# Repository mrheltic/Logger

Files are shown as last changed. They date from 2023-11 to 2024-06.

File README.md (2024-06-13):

# Logger










## 📝 Table of Contents
- [About](#🧐-about)
- [Getting Started](#🏁-getting-started)
- [Hardware](#🔧-hardware-required)
- [Description](#description)
- [Theoretical Notions](#theoretical-notions)
- [Code](#⌨️-code)
- [Display Mode](#🖥️-display-mode)
- [SD Mode](#💾-sd-mode)
- [Serial Mode](#💻-serial-mode)
- [Built using](#⛏️-built-using)
- [Contributing](#🫂-contributing)
- [Authors](#✍️-authors)
- [Repo Activity](#repo-activity)
- [License](#license)
- [Acknowledgments](#🎉-acknowledgments)

## 🧐 About
This project is a data acquisition system built using an ESP32 microcontroller board. The system incorporates an ADS1115 analog-to-digital converter, an SSD1306 display, and three buttons for user interaction. It is designed to store data on an SD card or send it to a pc for further analysis.

### Features

- Acquisition of analog sensor data using ADS1115 ADC
- Real-time display of sensor readings on SSD1306 OLED display
- User interaction through three buttons for control and configuration
- Storage of acquired data on an SD card for offline access
- Transmission of data to a computer for centralized analysis

## 🔧 Hardware Required

## 🏁 Getting Started

### Prerequisites

- Arduino IDE or Visual Studio Code (with PlatformIO)
- ESP32 board manager for Arduino IDE
- Libraries:
  - Adafruit ADS1X15 (for ADS1115)
  - Adafruit SSD1306 (for SSD1306 display)
  - SD (for SD card storage)
  - <other libraries as required>

### Installation

<details open>
<summary><i>Installation using Arduino IDE</i></summary>

- Clone or download the project repository from GitHub.
- Open the Arduino IDE and install the ESP32 board manager if not already installed.
- Connect the hardware components as per the provided circuit diagram.
- Install the required libraries using the Arduino Library Manager.
- Upload the code to the ESP32 board using the Arduino IDE.
- Monitor the serial output to ensure successful connection to the sensors.
- Verify the functionality by checking the sensor readings on the SSD1306 display and the data storage on the SD card.
</details>

<details open>
<summary><i>Installation using Visual Studio Code</i></summary>

- Clone or download the project repository from GitHub.
- Open VS and compile the software (changing the details on platform.ini according to your hardware).
- Connect the hardware components as per the provided circuit diagram.
- Upload the code to the ESP32 board using the upload tool.
- Monitor the serial output to ensure successful connection to the sensors.
- Verify the functionality by checking the sensor readings on the SSD1306 display and the data storage on the SD card.

</details>

## Description

## ⌨️ Code

All the code was written using the arduino Framework, for an ESP32. This gave us significant advantages in terms of ease of writing, online documentation, and especially in terms of click-through, which is considerably greater than for an arduino Uno. We followed a kind of MVC model, where each component is separate from the others and deals only with the things it is responsible for, invoking higher-level primitives. This allowed us to manage different components more smoothly.

### Main

The main substantially is a method wrapper and deals at a higher level with handling scrolling through the various menus. Initially (in setup) it asks the controller to initialize devices (the basic ones, such as buttons, screen, ...)

```cpp
while (!initializeDevices()){
}

updateMenu();
```

After this handles menu selection

```cpp
if (stateMenu)
{
  if (goDown())
  {
    menu++;
  }
  if (goUp())
  {
    menu--;
  }
  if (select())
  {
    executeAction(); //Enters in the selected menu
  }
}
```

### Controller

The controller is the component that manages all component behavior and is directly responsible for making measurements. Besides that it initializes all the devices and the serial. The initializations that are done can be blocking or non-blocking, depending on the type of component we want to initialize: a failure of the fundamental components results in a program block inside a loop, which will not allow the execution of the remaining code, while the other components may not be initialized at all. The reference with respect to the success or failure of initialization we have it by returning a boolean value true when the method is terminated, so it does not take into account subsequent failures. The whole initial part is devoted to declaring all pins connected to the board, and in case of custom configurations they can be changed before compilation. 

After all parameters have been selected, data acquisition will proceed. This involves an initial setup phase, in which, based on what parameters are selected (saved as global variables in the controller) it will go to set the mode (and consequently the channels to read from), the data rate, and calculate gain and offset. Depending on the output selected it could change significantly, but we will also have an output on the serial that tells us what is happening. Also in this part I am going to initialize the measurement object, which will handle the calculations made for mean and std.

```cpp
void adcSetup()
{
  setRate(currentSampleRate); //Physically setting the sample rate with ADS function
  setChannel(); //Setting the channel, gain and other useful parameters

  K_value = calculateCoefficient();
  O_value = calculateOffset();

  Measurement measurement(currentSampleRate); //Instantiate the object
}
```

After running the setup you enter the loggerAct, which is the method that takes care of the measurement. Here, depending on the mode that will be selected it will have different behavior, but basically what it does is:

```cpp
// The microcontroller is waiting for an interrupt from the ADC
if (!new_data)
  {
    return;
  }

// When the adc is alerted via the alert pin the code continues

if (!measurement.isArrayFull())
  {
    measurement.insertMeasurement(adcValue); // Get the misuration and stores in the array
  }

else
  {
    measurement.setArrayFull(false); // Empties the array and compute mean and std
    loggerGraphic(mode, channel, timestamp, mean); // Print on display the parameters
  }

new_data = false;
```

### View

The view component deals with screen management. Here it is initialized and passing it the necessary parameters updates the screen. Bipmap images of the various modes and associated sliders are also saved here. The view also provides functions to be used directly by the controller, such as the one used during the loggerAct, which takes care of printing media (for each second), timestamp, mode, and output

### Model

The model is the component that manages the "measurements" class and takes care of the array. This provides various functions to calculate different values useful for measurements, such as mean and standard deviation. In fact, when we go to initialize the object an array is created, of length equal to the data rate, and we go to calculate mean and std for each second. Each time the adc returns us the value, from the controller, we go to invoke a function that is used to insert the measured value (already possibly multiplied by the gain and summed with the offset) at the tail of the array. 

```cpp
class Measurement
{
private:
    int *measurements;
    float mean;
    float std; 
    bool arrayFull;

public:
    Measurement(int len);
    ~Measurement();
    void insertMeasurement(int value);
    void calculateMean();
    void calculateStd();
    void reset();
    bool isArrayFull();
    int getLength();
};
```

## Theoretical Notions
<details open>
<summary><i>Adc</i></summary>
In this project we use the ADS1115 that is a very small, low-power, 16-bit, delta-sigma (ΔΣ) analog-to-digital converters (ADCs).
There are many ADCs available on the market for various applications: Ramping, SAR, delta-sigma, Flash and so on. 
ΔΣ ADCs are now ideal for converting analog signals over a wide range of frequencies, from DC to several megahertz. Basically, these converters consist of an oversampling modulator followed by a digital filter that together produce a high-resolution data-stream output. The ADS1115 has an adjustable gain(PGA), an interal voltage reference, a clock oscillator, an I2C interface, and also a programmable digital comparator that provides an alert on a dedicated pin. The latter played an important role in carrying out the sampling at the maximum achievable speed of 860SPS. Thanks to the mux the adc has four single-ended(to measure
each channel with respect to ground) or two differential inputs and two available conversion mode: single-shot mode(power saving mode) and continuous mode. In continuous conversion mode, the adc automatically begins a conversion of the input as soon as the previous conversion is completed and the rate is programmed by software.
To achieve high accuracy measurements it's a mandatory following several step:

- Use the Maximum Resolution in the readings
- Adjust the PGA to match the voltage range of your input signal(all specifications can be found in the datasheet)
- Use an external voltage reference instead of the integrated
- Implement appropriate filtering and signal conditioning techniques to minimize noise and Interference
- Periodically calibrate the system to compensate any drift
- Avoid common source of error such as impedance mismatches
- Select data rate based on dynamic meausurements or slow signals
- Minimize signal path lengths.
</details>

## 🖥️ Display Mode

### Usage

### Performance Evaluation

## 💾 SD Mode

### Usage

### Performance Evaluation

## 💻 Serial Mode

### Usage

### Explanation

In the data acquisition stage, data is sent to the pc, which is processed through python. The manufacturer of the module, in the datasheet indicates that the conversion time is exactly equivalent to 1/DR (worst case: 860SPS), so there will certainly be a small delay due to data processing due to the microcontroller. This, in turn, will have to be added to a time, albeit very small, due to communication via serial. We had initially opted to send the data via the `Serial.println()` function, but this route, following some testing, seemed impractical. This was because, while having a readable result directly from the serial would have made it easy and intuitive to retrieve the data, it introduced a considerable delay, far in excess of the 1/DR value, even orders of magnitude (about tenths of a second). We therefore opted for the `Serial.write()` function, but again there were problems, since the measured values are 16-bit integers, so they needed to be split in two and sent (so as to send 8 bits at a time). 

```cpp
Serial.write(0xCC);                   // Start byte
Serial.write((ADCvalue >> 8) & 0xFF); // High byte
Serial.write(ADCvalue & 0xFF);       // Low byte
```
- `Serial.write(0xCC)` sends a start byte. The Serial.write() function writes binary data to the serial port. 0xCC is the hexadecimal representation of the start byte. The microcontroller need to send this to communicate that a new set of data is starting.

- `Serial.write((ADCvalue >> 8) & 0xFF)` sends the high byte of ADCvalue. The >> 8 operation shifts the bits of ADCvalue 8 places to the right, effectively moving the high byte to the position of the low byte. The & 0xFF operation then masks the lower byte, so only the original high byte of ADCvalue remains.

- `Serial.write(ADCvalue & 0xFF)` sends the low byte of ADCvalue. The & 0xFF operation masks the high byte of ADCvalue, so only the low byte remains.

After the microcontroller sends the measured value this way, python will have to deal with reconstructing it and converting it to a readable value, like this:

```python
start_byte = ser.read(1)  # Read the start byte
    if start_byte == b'\xCC':  # Verify the start byte
        high_byte = ser.read(1)  # Read the high byte
        low_byte = ser.read(1)  # Read the low byte
        measurement = (ord(high_byte) << 8) | ord(low_byte)  # Merge the bytes
```

- `start_byte = ser.read(1)` reads one byte from the serial port and assigns it to the variable start_byte.

- `if start_byte == b'\xCC'` checks if the start byte is equal to b'\xCC', which is the byte representation of the hexadecimal number 0xCC. If the start byte is 0xCC, the code inside the if statement will be executed. This is used to verify that the data transmission is starting correctly.

- `high_byte = ser.read(1)` reads the next byte (after the start byte) from the serial port, which is the high byte of the measurement.

- `low_byte = ser.read(1)` reads the next byte from the serial port, which is the low byte of the measurement.

- `measurement = (ord(high_byte) << 8) | ord(low_byte)` merges the high byte and the low byte to reconstruct the original measurement. The `ord()` function is used to get the integer value of a byte. The `<< 8` operation shifts the bits of the high byte 8 places to the left, effectively moving it to the position of the high byte in a 16-bit number. The `|` operation is a bitwise OR, which combines the high byte and the low byte into a single 16-bit number.

For more in-depth information you can visit the python code repository directly: [Serial Mode Logger](https://github.com/mrheltic/Serial-Mode-Logger)

### Performance Evaluation

## ⛏️ Built Using
- [PlatformIO](https://platformio.org) - PlatformIO
- [Arduino Framework](https://www.arduino.cc) - Arduino Framework

## 🫂 Contributing

Contributions to this project are welcome. If you encounter any issues or have ideas for improvements, please submit a pull request or open an issue on the project repository.

## ✍️ Authors
- [@mrheltic](https://github.com/mrheltic) - Florio Vincenzo Pio
- [@Phersax](https://github.com/Phersax) - Stasi Francesco
- [@murcie443](https://github.com/murcie443) - Tonti Davide

## Repo Activity

Repobeats analytics image

## License
Details about the license.

## 🎉 Acknowledgments
Any acknowledgments (optional).

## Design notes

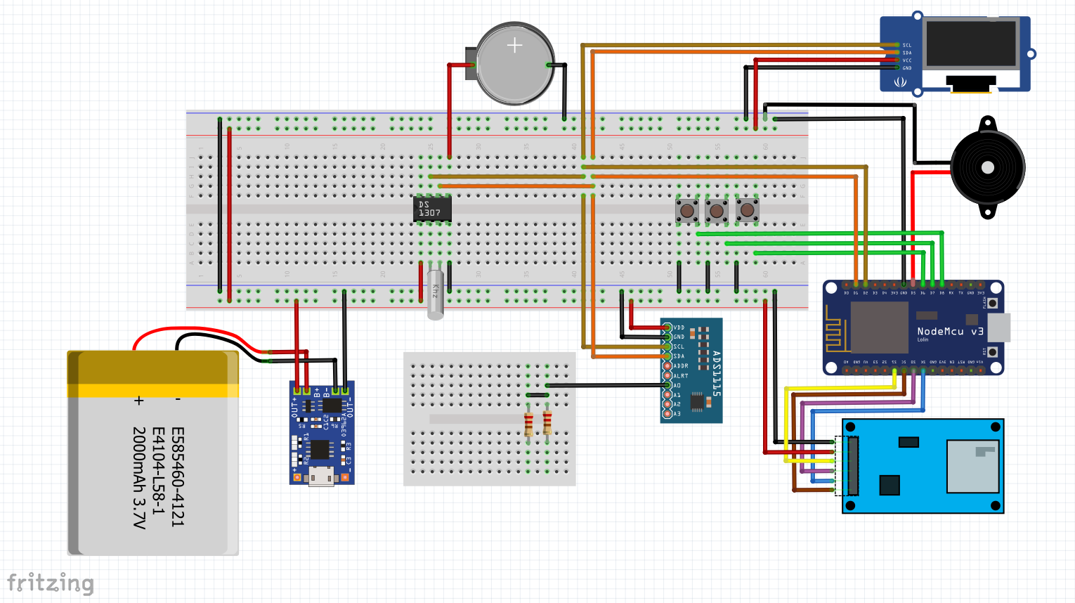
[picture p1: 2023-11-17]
medias/schematico.png

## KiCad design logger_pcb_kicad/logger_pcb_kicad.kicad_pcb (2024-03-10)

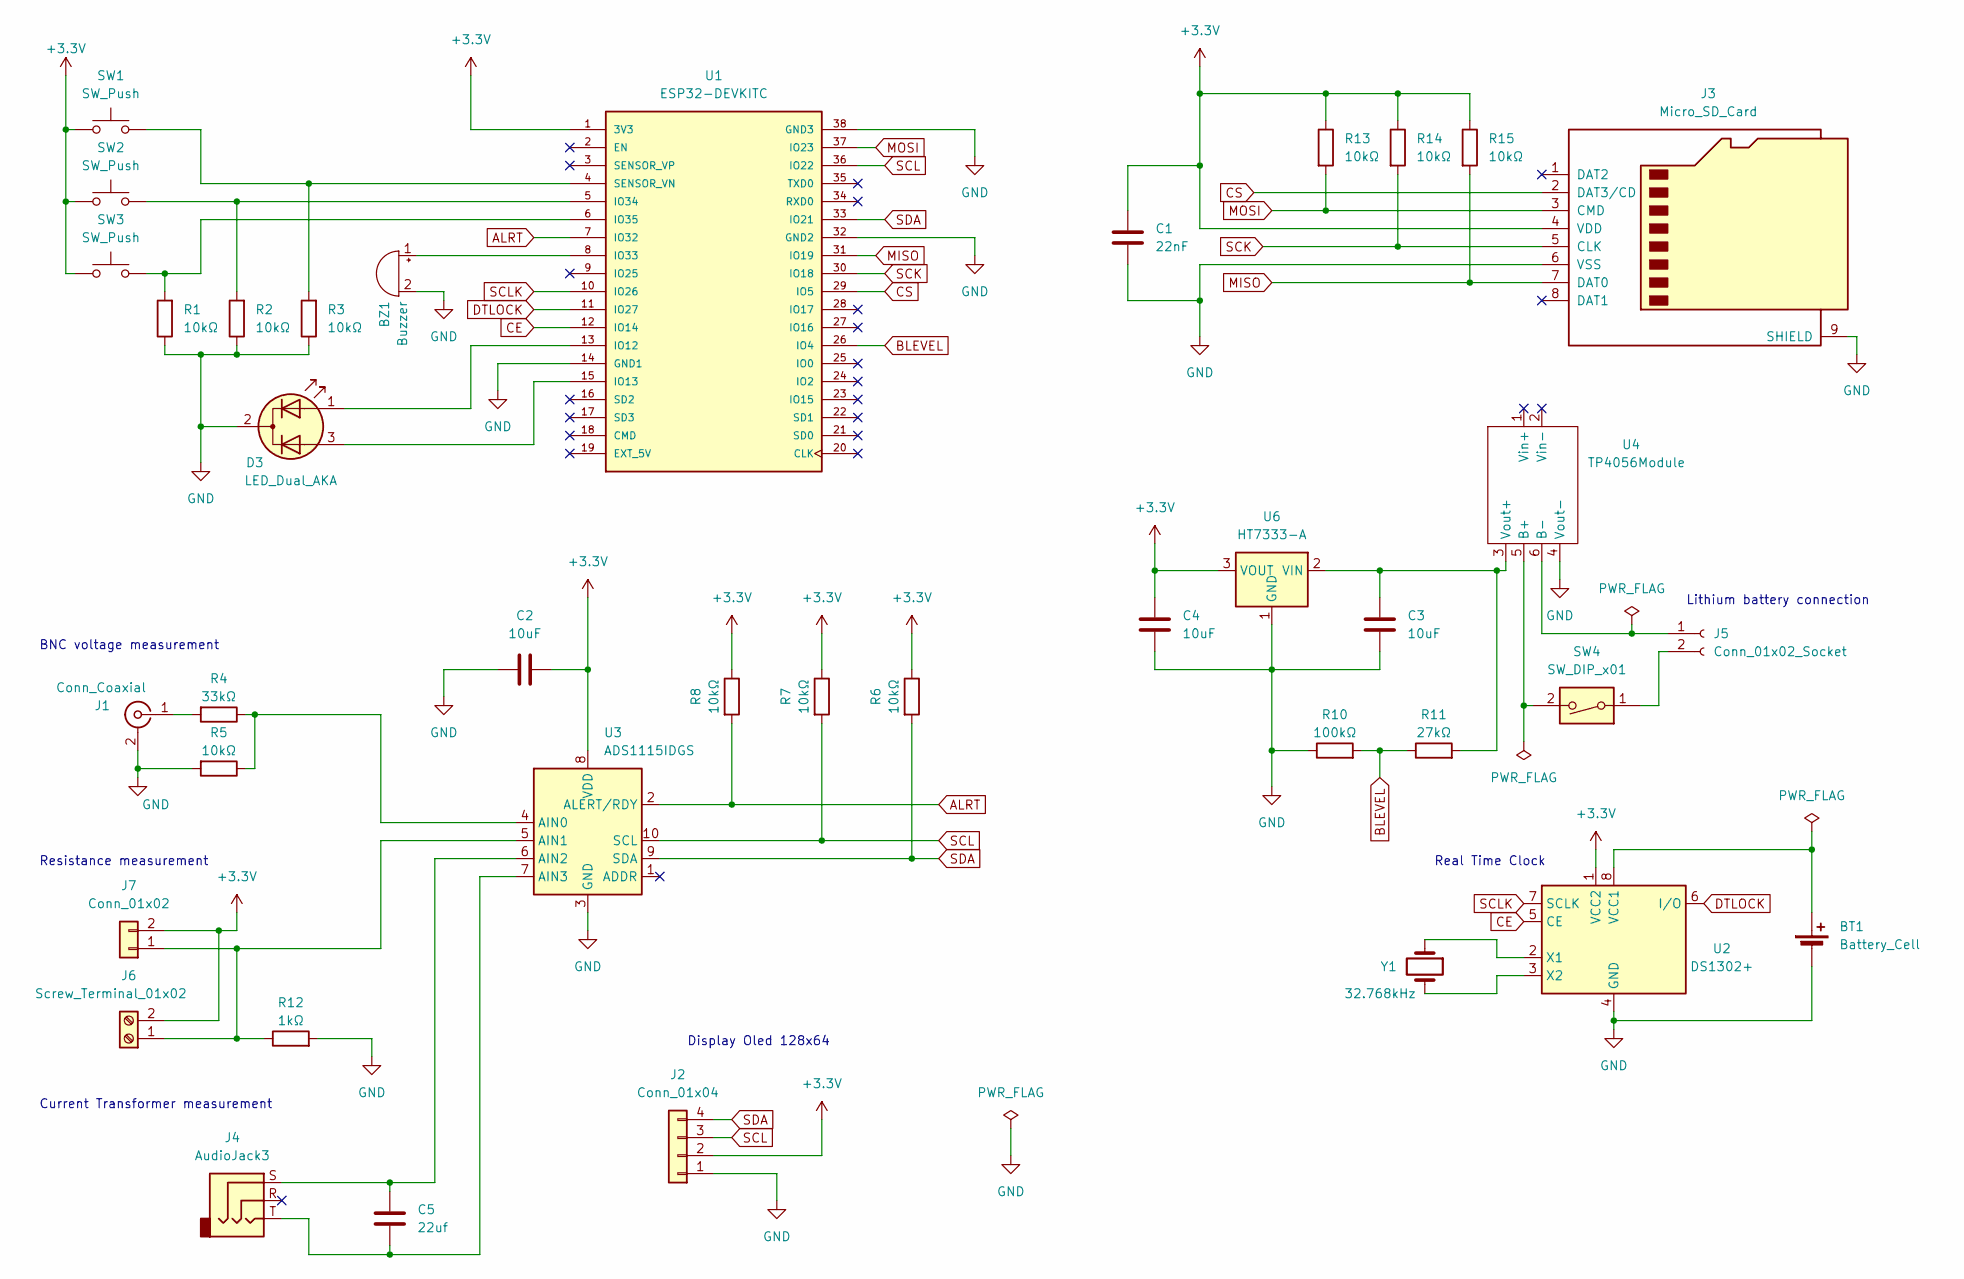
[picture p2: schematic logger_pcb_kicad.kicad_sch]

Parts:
BT1: Battery_Cell; Battery_holder_cr2032
BZ1: Buzzer; Buzzer_12x9.5RM7.6
C1: 22nF; C_0805_2012Metric
C2, C3, C4: 10uF; C_0805_2012Metric
C5: 22uf; C_0805_2012Metric
D3: LED_Dual_AKA; LED_D3.0mm-3
J1: Conn_Coaxial; BNC_TEConnectivity_1478035_Horizontal
J2: Conn_01x04; 128x64OLED
J3: Micro_SD_Card; J_SD_Card-micro_socket_A
J4: AudioJack3; Jack_3.5mm_CUI_SJ1-3525N_Horizontal
J5: Conn_01x02_Socket; JST_EH_B2B-EH-A_1x02_P2.50mm_Vertical
J6: Screw_Terminal_01x02; TerminalBlock_Altech_AK300-2_P5.00mm
J7: Conn_01x02; PinHeader_1x02_P2.54mm_Vertical
R1, R2, R3, R6, R7, R8, R13, R14, R15: 10kΩ; R_1206_3216Metric
R4: 33kΩ; R_Axial_DIN0207_L6.3mm_D2.5mm_P10.16mm_Horizontal
R5: 10kΩ; R_Axial_DIN0207_L6.3mm_D2.5mm_P10.16mm_Horizontal
R10: 100kΩ; R_Axial_DIN0207_L6.3mm_D2.5mm_P10.16mm_Horizontal
R11: 27kΩ; R_Axial_DIN0207_L6.3mm_D2.5mm_P10.16mm_Horizontal
R12: 1kΩ; R_Axial_DIN0207_L6.3mm_D2.5mm_P10.16mm_Horizontal
SW1, SW2, SW3: SW_Push; SW_PUSH-12mm
SW4: SW_DIP_x01; SW_CuK_JS202011AQN_DPDT_Angled
U1: ESP32-DEVKITC; MODULE_ESP32-DEVKITC; PARTREV N/A
U2: DS1302+; DIP-8_W7.62mm
U3: ADS1115IDGS; TSSOP-10_3x3mm_P0.5mm
U4: TP4056Module; TP4056-18650
U6: HT7333-A; SOT-89-3
Y1: 32.768kHz; Crystal_C38-LF_D3.0mm_L8.0mm_Horizontal

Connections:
+3.3V: C1.1, C2.1, C4.1, J2.2, J3.4 (VDD), J6.2, J7.2, R6.1, R7.1, R8.1, R13.1, R14.1, R15.1, SW1.1, SW2.1, SW3.1, U1.1 (3V3), U2.1 (VCC2), U3.8 (VDD), U6.3 (VOUT)
ALRT: R8.2, U1.7 (IO32), U3.2 (ALERT/RDY)
BLEVEL: R10.2, R11.1, U1.26 (IO4)
CE: U1.12 (IO14), U2.5 (CE)
CS: J3.2 (DAT3/CD), U1.29 (IO5)
DTLOCK: U1.11 (IO27), U2.6 (I/O)
GND: BT1.2 (-), BZ1.2 (+), C1.2, C2.2, C3.2, C4.2, D3.2 (K), J1.2 (Ext), J2.1, J3.6 (VSS), J3.9 (SHIELD), R1.1, R2.1, R3.1, R5.2, R10.1, R12.2, U1.14 (GND1), U1.32 (GND2), U1.38 (GND3), U2.4 (GND), U3.3 (GND), U4.4 (Vout-), U6.1 (GND)
MISO: J3.7 (DAT0), R15.2, U1.31 (IO19)
MOSI: J3.3 (CMD), R13.2, U1.37 (IO23)
unnamed: BT1.1 (+), U2.8 (VCC1)
unnamed: BZ1.1 (-), U1.8 (IO33)
unnamed: D3.1 (A1), U1.13 (IO12)
unnamed: D3.3 (A2), U1.15 (IO13)
unnamed: J1.1 (In), R4.2
unnamed: J5.1, U4.6 (B-)
unnamed: J5.2, SW4.1
unnamed: J6.1, J7.1, R12.1, U3.5 (AIN1)
unnamed: R2.2, SW2.2, U1.5 (IO34)
unnamed: R1.2, SW3.2, U1.6 (IO35)
unnamed: R3.2, SW1.2, U1.4 (SENSOR_VN)
unnamed: U2.2 (X1), Y1.1
unnamed: U2.3 (X2), Y1.2
unnamed: R4.1, R5.1, U3.4 (AIN0)
unnamed: C5.1, J4.S, U3.6 (AIN2)
unnamed: C5.2, J4.T, U3.7 (AIN3)
unnamed: SW4.2, U4.5 (B+)
unnamed: C3.1, R11.2, U4.3 (Vout+), U6.2 (VIN)
SCK: J3.5 (CLK), R14.2, U1.30 (IO18)
SCL: J2.3, R7.2, U1.36 (IO22), U3.10 (SCL)
SCLK: U1.10 (IO26), U2.7 (SCLK)
SDA: J2.4, R6.2, U1.33 (IO21), U3.9 (SDA)

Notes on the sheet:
BNC voltage measurement
Real Time Clock
Current Transformer measurement
Resistance measurement
Display Oled 128x64
Lithium battery connection

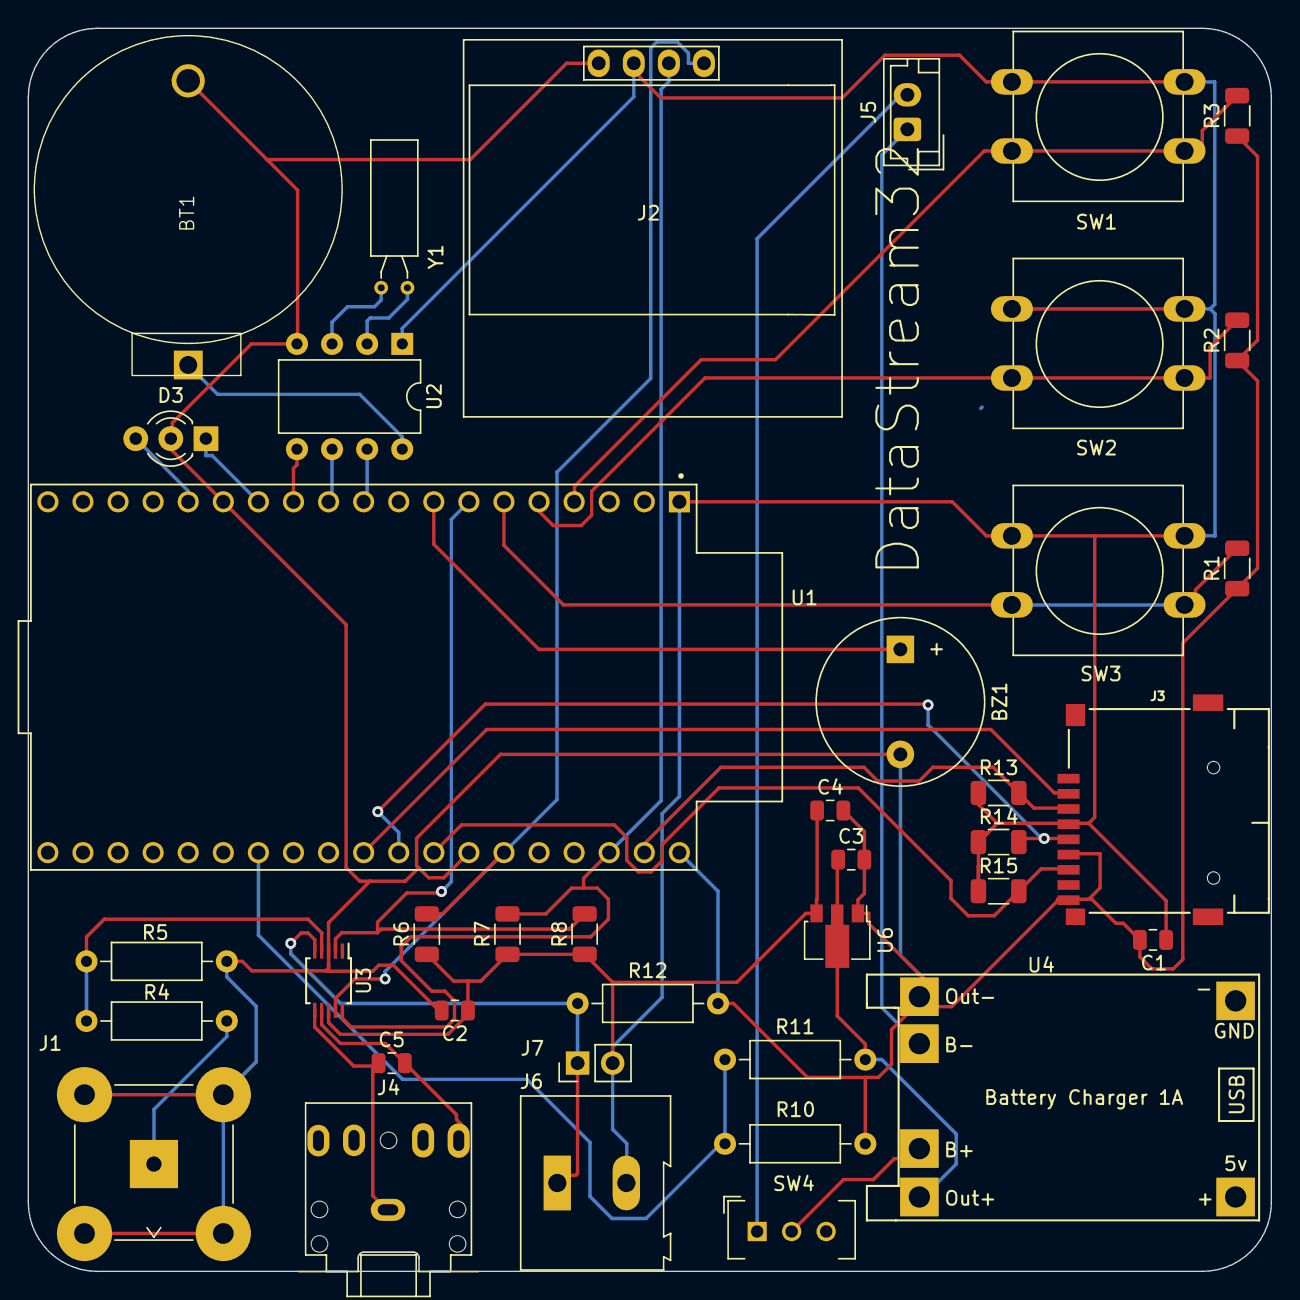
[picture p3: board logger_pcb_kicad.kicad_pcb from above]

Board: 2 copper layers, 90.0 x 90.0 mm, 39 parts (0 on the bottom side), 31 nets.

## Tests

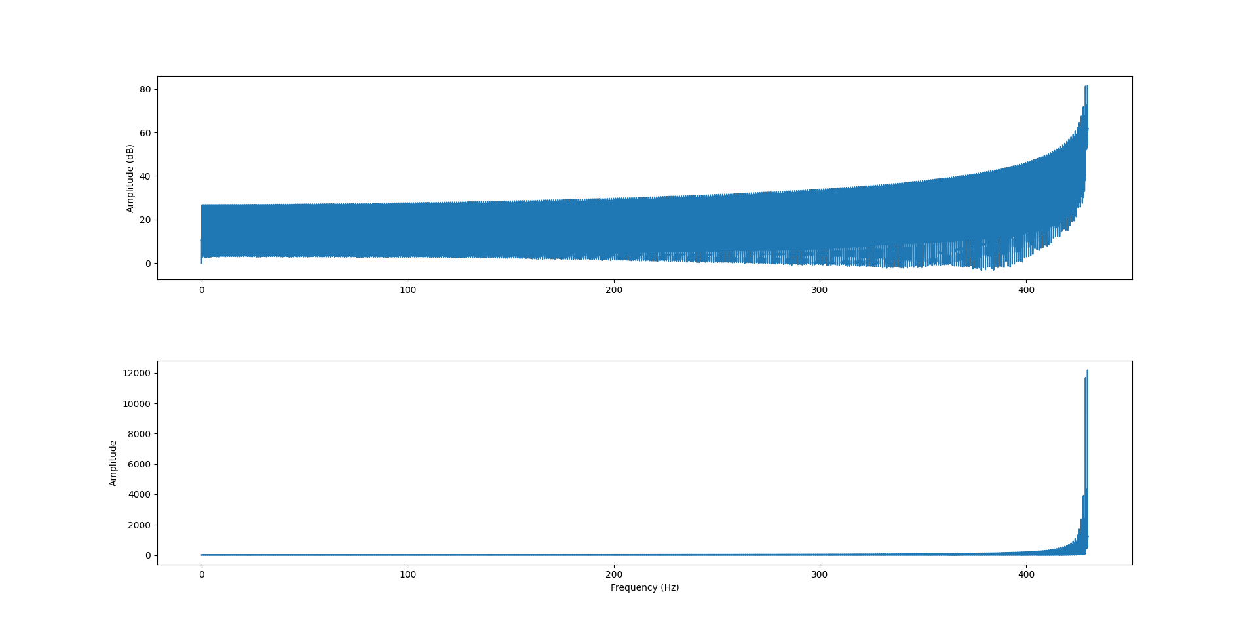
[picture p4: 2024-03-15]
Performance/Fft/sinusoidalfft5.png

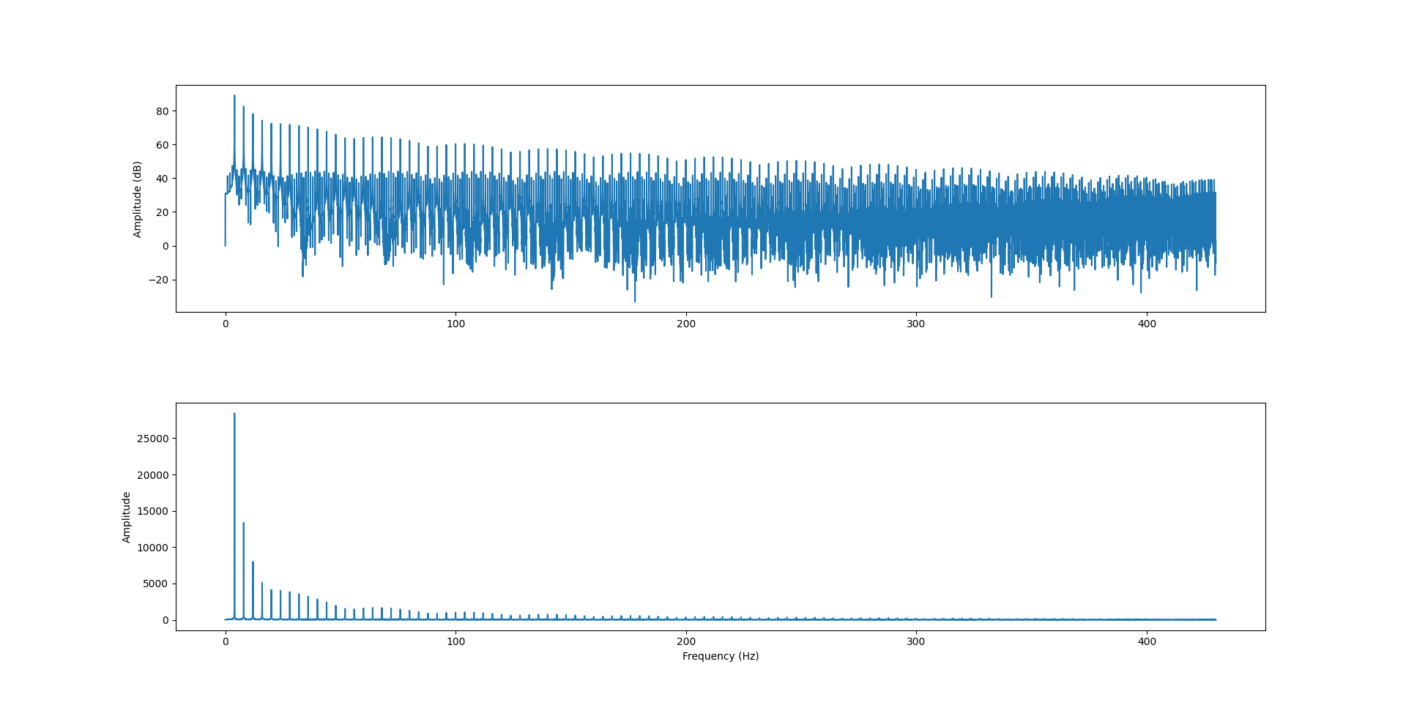
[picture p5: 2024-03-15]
Performance/Fft/rampfft1.png

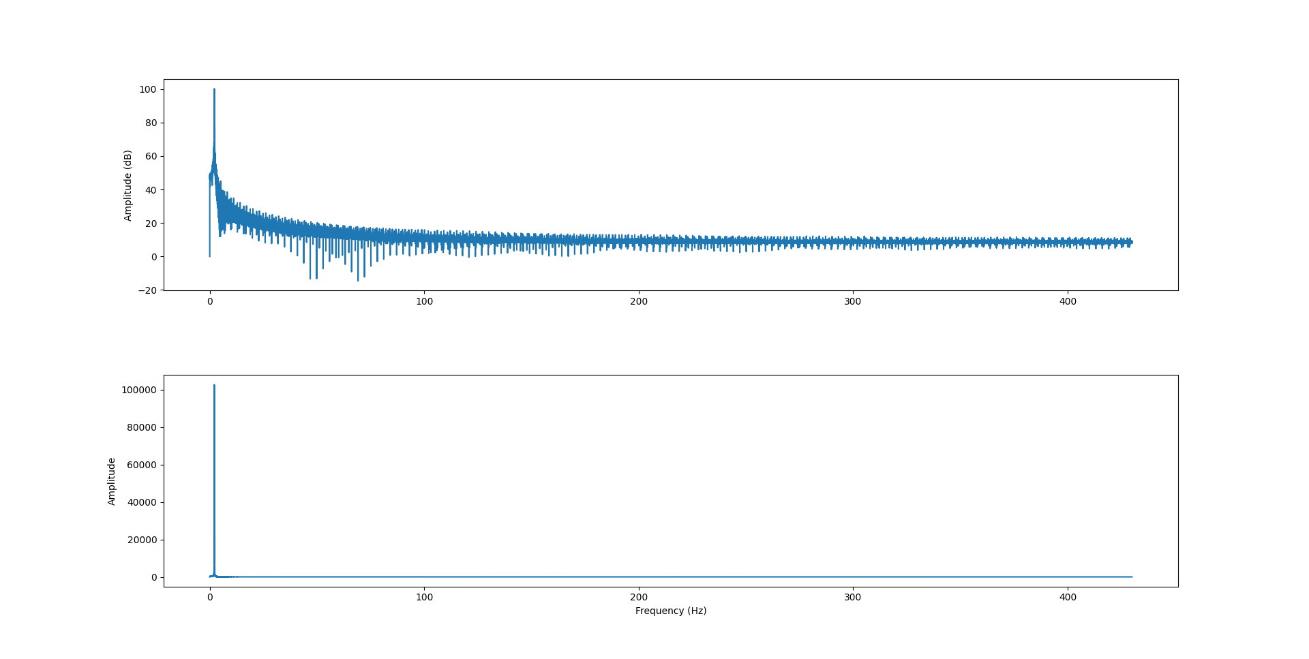
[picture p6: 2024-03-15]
Performance/Fft/sinusoidalfft7.png

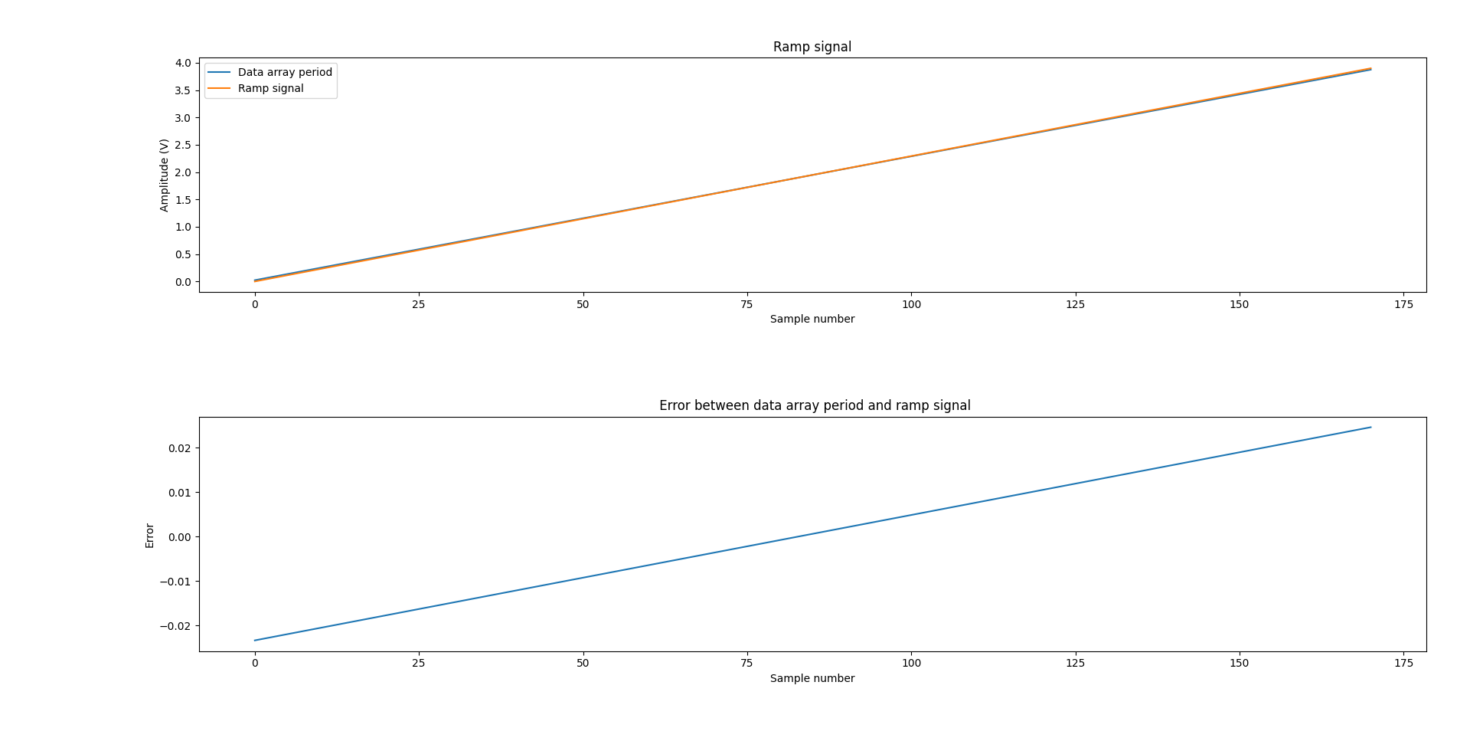
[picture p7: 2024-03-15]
Performance/Ramp/rampfit2.png

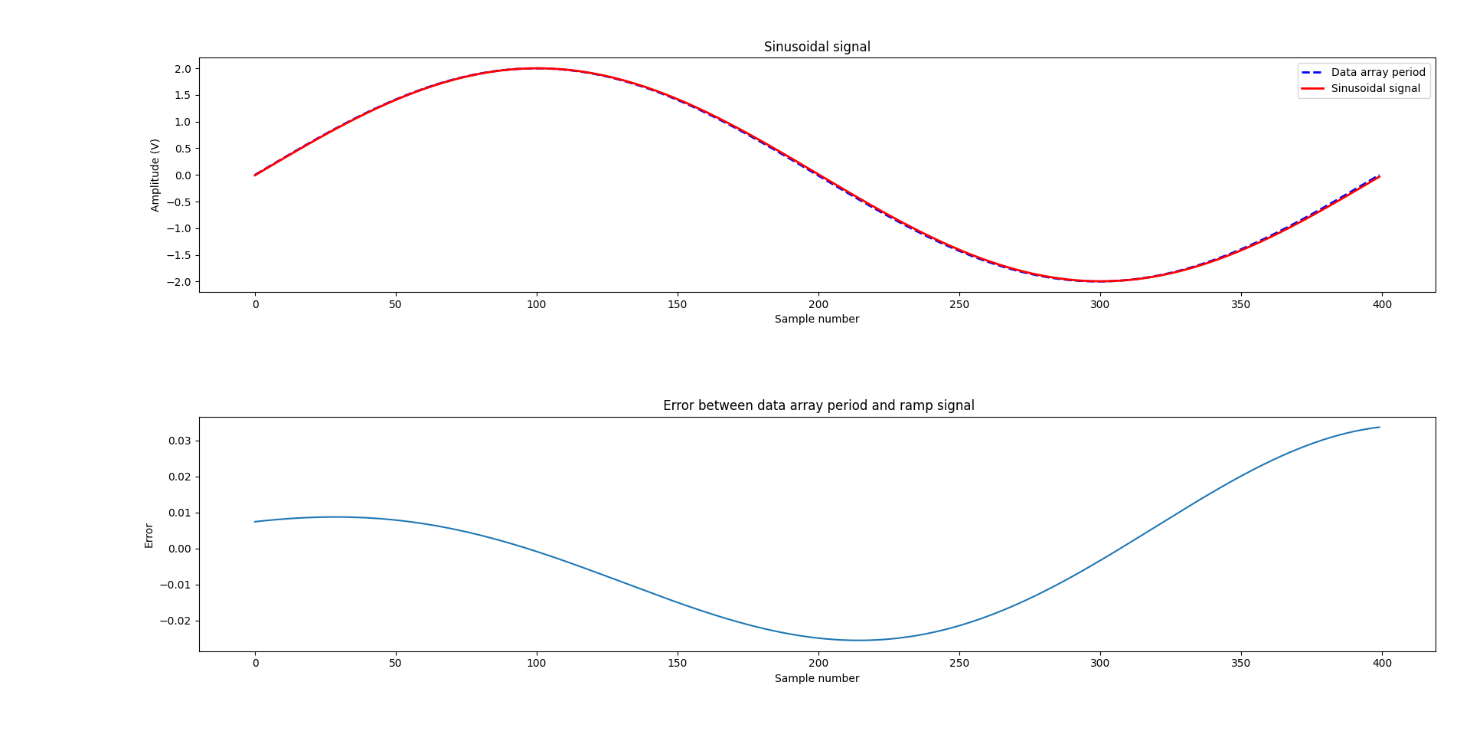
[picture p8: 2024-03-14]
Performance/Sinusoidal/siunsoidalfit.png

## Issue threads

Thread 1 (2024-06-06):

Is it possible to use it for high speed analog accelerometer logging?

Arakistech, 2024-06-06:
Is it possible to use it for high speed analog accelerometer logging?

mrheltic, 2024-06-17:
It depends on the speed you're talking about. Our logger has a max of 860sps (with a 16bit adc).

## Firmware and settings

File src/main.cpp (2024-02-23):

/***************************************************
 *  Logger
 *
 * Contributors:
 * - Vincenzo Pio Florio
 * - Francesco Stasi
 * - Davide Tonti
 *
 ***************************************************/

#include <Arduino.h>
#include "../include/view.h"
#include "../include/controller.h"

// STATE VARIABLES
int menu = 1;
boolean stateMenu = 1;
boolean subSetup = 1;

// Start submenu loops with controller actions
/**
 * Executes the selected action based on the value of the 'menu' variable.
 * The action is determined by the value of 'menu' and includes options like loggerAct, outputModeAct, inputModeAct, infoAct, and sampleSetAct.
 * After executing the action, it updates the menu and sounds the buzzer.
 */
void executeAction()
{
  switch (menu)
  {
  case 1:
    adcSetup();
    if (preliminaryControl())
    {
      switch (currentMode)
      {
      case 0:
        while (!select() && stateMenu == 0)
        {
          loggerActDisplay();
        }
        break;

      case 1:
        while (!select() && stateMenu == 0)
        {
          loggerActSerial();
        }
        break;

      case 2:
        while (!select() && stateMenu == 0)
        {
          loggerActSD();
        }
        break;
      }
    }
    else
    {
      if (currentMode == SD_ONLY)
        ESP.restart();
    }
    stateMenu = 1;
    break;
  case 2:
    while (!select() && stateMenu == 0)
    {
      outputModeAct();
    }
    stateMenu = 1;
    break;
  case 3:
    while (!select() && stateMenu == 0)
    {
      inputModeAct();
    }
    stateMenu = 1;
    break;
  case 4:
    while (!select() && stateMenu == 0)
    {
      infoAct(subSetup);
    }
    stateMenu = subSetup = 1;
    break;
  case 5:
    while (!select() && stateMenu == 0)
    {
      sampleSetAct();
    }
    stateMenu = 1;
    break;
  }
  soundBuzzer(selectFrequency, selectDuration);
  updateMenu(menu);
}

/**
 * @brief Initializes the devices and updates the menu.
 */
void setup()
{

  while (!initializeDevices())
  {
    delay(1000);
  }

  updateMenu(menu);
}

void loop()
{
  if (stateMenu)
  {
    if (goDown())
    {
      soundBuzzer(scrollFrequency, scrollDuration);
      menu++;
      menu = updateMenu(menu);
    }
    if (goUp())
    {
      soundBuzzer(scrollFrequency, scrollDuration);
      menu--;
      menu = updateMenu(menu);
    }
    if (select())
    {
      stateMenu = 0;
      soundBuzzer(selectFrequency, selectFrequency);
      executeAction();
    }
  }

  // delay(40);
  // Serial.print(menu);
}

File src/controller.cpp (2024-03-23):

#include <Arduino.h>
#include "../include/controller.h"
#include "../include/model.h"
#include "../include/view.h"
#include "FS.h"
#include "SD.h"
#include "SPI.h"
#include <WiFi.h>
#include <WebServer.h>
#include <Adafruit_ADS1X15.h>
#include <Adafruit_BusIO_Register.h>
#include <Ds1302.h>

// DECLARING VARIABLES FOR BUTTONS
#define DOWN_BUTTON 35
#define SELECT_BUTTON 34
#define UP_BUTTON 39

// DECLARING VARIABLES FOR RTC
#define PIN_ENA 14
#define PIN_CLK 26
#define PIN_DAT 27

// DECLARING VARIABLES FOR SPI
#define SCK 18
#define MISO 19
#define MOSI 23
#define CS 5

int16_t adcValue;

// Variables current measurement
const float FACTOR_I = 30;             // 30A/1V from teh current transformer
const float multiplier_I = 0.00003125; // for current measurement and gain four (1.024V / 2^16 * 2)
// const float multiplier_I = 0.000015625; // for current measurement and gain eight (0.512 / 2^16 * 2)

// Variables voltage measurement
const float FACTOR_V = 4.334335237;   // FACTOR_V = (R1 + R2) / R2    R1 resistor beetween Vin and A0 [ohm] and R2 resistor beetween A0 and GND [ohm]
const float multiplier_V = 0.0001875; // for voltage measurement and gain twothirds (6.144V / 2^16 * 2)
// const float multiplier_V = 0.000125;

// Variables resistance measurement
const float FACTOR_R = 999;          // FACTOR_R = R3 resistor beetween A1 and GND [ohm]
const float multiplier_R = 0.000125; // for voltage measurement and unit gain (4.096 / 2^16 * 2)

float K_value;
float O_value;

const static char *WeekDays[] =
    {
        "Monday",
        "Tuesday",
        "Wednesday",
        "Thursday",
        "Friday",
        "Saturday",
        "Sunday"};

// DECLARING VARIABLES FOR OUTPUT DEVICES
#define BUZZER 33
#define LED1 12
#define LED2 13
int scrollFrequency = 200;
int scrollDuration = 200;
int selectFrequency = 200;
int selectDuration = 200;

// DECLARING VARIABLES FOR ADS
#define ALERT_PIN 32

int dataRateValues[] = {8, 16, 32, 64, 128, 250, 475, 860};

// DECLARING VARIABLES FOR MODE AND CHANNEL DEFAULT CONTIONS
MODE currentMode = SERIAL_ONLY;
CHANNEL currentChannel = VOLTAGE;
String currentChannelString = "Voltage"; // Used to communicate the current channel to the user through the serial

int currentSampleRate = 860;

// DECLARING VARIABLES FOR EMPHIRICALLY EVALUATE PERFORMANCES
unsigned long serialWaitingTime = 0;
unsigned long time_now = 0;
String currentTime;

// DECLARING TIMEOUT RESPONSE SERIAL
#define TIMEOUT 10000

// DECLARING THE OBJECT OF MEASUREMENTS
Measurement measurement(8);

// DECLARING VARIABLES FOR SD CARD
File file;

#ifndef IRAM_ATTR
#define IRAM_ATTR
#endif

/**
 * @brief Indicates whether new data is available.
 */
volatile bool new_data = false;
/**
 * @brief Interrupt service routine for handling new data ready event.
 *
 * This function is called when new data is ready to be processed.
 * It sets the `new_data` flag to true.
 */
void IRAM_ATTR NewDataReadyISR()
{
    new_data = true;
}

// DECLARING VARIABLES FOR WIFI
const char *ssid = "Logger-Access-Point";
const char *password = "logger1234";

bool isExecuted = false;

// DECLARING RTC
Ds1302 rtc(PIN_ENA, PIN_CLK, PIN_DAT);

// DECLARING ADC
Adafruit_ADS1115 ads;

const char *creditString = "-------------------------------\nLogger\n-------------------------------\nContributors:\n- Vincenzo Pio Florio\n- Francesco Stasi\n- Davide Tonti\n-------------------------------\n";

/**
 * @brief Initializes the serial monitor.
 *
 * This function initializes the serial monitor with a baud rate of 115200.
 * It waits for the serial port to connect before proceeding.
 * It also prints an "Initializing..." message to the serial monitor.
 */
void initializeSerial()
{
    // INITIALIZING SERIAL MONITOR
    Serial.begin(115200);

    while (!Serial)
    {
        ; // wait for serial port to connect. Needed for native USB port only
    }
    // Print contributors
    // Serial.println(creditString);
}

/**
 * @brief Initializes the output devices.
 *
 * This function initializes the output devices by setting the pinMode of the BUZZER pin to OUTPUT.
 *
 * @return true if the output devices are successfully initialized, false otherwise.
 */

boolean initializeOutputDevices()
{
    // Serial.println("Initializing output devices...");

    pinMode(BUZZER, OUTPUT);
    pinMode(LED1, OUTPUT);
    pinMode(LED2, OUTPUT);

    // Serial.println("Output devices initialized\n");

    return true;
}

/**
 * @brief Initializes the input devices.
 *
 * This function sets the pin modes for the UP_BUTTON, SELECT_BUTTON, and DOWN_BUTTON pins to INPUT.
 *
 * @return true if the input devices are successfully initialized, false otherwise.
 */
boolean initializeInputDevices()
{

    // Serial.println("Initializing input devices...");

    pinMode(UP_BUTTON, INPUT);
    pinMode(SELECT_BUTTON, INPUT);
    pinMode(DOWN_BUTTON, INPUT);

    // Serial.println("Input devices initialized\n");

    return true;
}

boolean initializeSDcard()
{
    // Serial.println("Initializing SD card...\n");

    SPI.begin(SCK, MISO, MOSI, CS);

    if (!SD.begin(CS, SPI))
    {
        // Serial.println("Card Mount Failed");
        return false;
    }
    else
    {
        logfileSDcard();
    }
    return true;
}

void logfileSDcard()
{

    if (SD.exists("/dataStorage.ds32")) // if the file exists it'll be removed
    {
        SD.remove("/dataStorage.ds32");
    }

    // Serial.println("Creating dataStorage.ds32..."); // create and open the file ready to be written
    writeFile(SD, "/dataStorage.ds32", "");
    writeFile(SD, "/creditsFile.txt", creditString);
}

void writeFile(fs::FS &fs, const char *path, const char *message)
{
    // //Serial.printf("Writing file: %s\n", path);

    File file = fs.open(path, FILE_WRITE);
    if (!file)
    {
        // Serial.println("Failed to open file for writing");
        return;
    }
    if (file.print(message))
    {
        // //Serial.println("File written");
    }
    else
    {
        // //Serial.println("Write failed");
    }
    file.close();
}

void appendFile(fs::FS &fs, const char *path, const char *message)
{
    File file = fs.open(path, FILE_APPEND);
    /*
    if (!file)
    {
        // //Serial.println("Failed to open file for appending");
        return;
    }
    if ()
    {
        // //Serial.println("Message appended");
    }
    else
    {
        // //Serial.println("Append failed");
    }
    */
    file.print(message);
    file.close();
}

boolean initializeRTC()
{
    rtc.init();
    return true;
}
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

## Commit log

2023-10-26 v0.1.1
    Added ADS initialization
    Added debug printing on display and serial
    Refactoring
2023-11-09 display init
    added:
    menu structure
    bitmap menu
    bitmap input e output mode
    basic menu navigation in the loop
    [logger schema.fzz]
2023-11-11 Loop structure
    Loop structure
    variable state
    fixed some functions
    [controller.cpp, main.cpp]
2023-11-11 v0.2.0
    Added:
    graphic functions
    action functions
    submenu sample rate set
    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
2023-11-13 v0.2.1
    Some functions have been renamed.
    Submenus have been created to select the input and output modes.
    The delay after button presses has been entered into the soundBuzzerScroll() and soundBuzzerSelect() functions.
2023-11-17 Update platformio.ini
    ESP32 <- nodeMCU v3 (ESP12-E)
2023-11-17 v0.2.2
    -Board change
    -Added toString method for setting Rate
    -Organized headers
2023-12-02 Added documentation💀
2023-12-05 a0.2.3
    -Measurements test
    -Added Serial commands
    -Started to take adc values
    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
2023-12-12 General Hotfixes
    - Fixed Differemtial mode
    - Fixed a bug (missing break)
    - Starting to add docs to some revamped function
    [controller.cpp]
2023-12-13 d0.2.3
    - Fixed some logical error
    - Removed libs from gitignore
    [controller.cpp]
2023-12-13 v0.2.4
    Some fixes:
    - Ads setup
    - Made changes on logic
    [controller.cpp, main.cpp]
2023-12-17 Added RTC
    RTC has been added and a method for obtaining string format times.
    The loggergraphic function has been changed to receive the string containing the current time
2023-12-17 fixed bug about "channel" and "mode"
    [controller.cpp]
2023-12-17 General Hotfixes
    - Missing semicolons
    - Fixed toString methods
    [controller.cpp]
2023-12-18 Very important update in the logger code!!!!!!!!!!!
    Changed:
    -Data rate setting (TODO)
    -Fixed general bugs on timings
    [controller.cpp]
2023-12-19 v0.3.1
    -SPI comunication library
    -SD function for storage data in .txt file
    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
2023-12-19 Revert "Co-authored-by: dav01luffy <dav01luffy@users.noreply.github.com>"
    This reverts commit 52559b9f94277b24b1968871d376b47ae81394ab, reversing
    changes made to ef256c03d0432c210b413ccbfa4b5324dc4ea9b2.
    [controller.cpp]
2023-12-19 v0.3.2
    Added switch case to select mode
2023-12-19 Fixes
    -delete useless lines
    [controller.cpp]
2023-12-20 error graphic funtion and device control
    [controller.cpp, main.cpp]
2023-12-23 v0.3.2
    -function to preliminary control in logger sub-menu
    -SD begin
    -SPI begin
    ATTENTION: micro sd not working
    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
    [controller.cpp, main.cpp]
2023-12-24 v0.3.4
    Problema SD risolto (attenzione alla libreria ledc)
    Primo test di misura in tensione
    Aggiornata la funzione loggerGraphic()
    [controller.cpp]
2023-12-27 Test for the measure in current
    -Calculation of constant variables for measurement
    -Current measurement test
    -Update ADS setup
    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
2024-02-20 v0.4.0
    - Added Serial
    - Fixed controller
    [controller.cpp]
2024-02-20 Added docs
    I'm tired D;
2024-02-21 Fixed Buzzer
    -Correct the buzzer pin
    -Adding Function for Buzzer and variables to manage the sound
    [controller.cpp, main.cpp]
2024-02-21 readme adc
    -add brief summary
2024-02-22 v1.0.1
    -loggeract functions
    -coefficients to convert voltage measure
    -fixed some problem with Serial and SD mode
    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
    [controller.cpp, main.cpp]
2024-02-22 control result and problems
    [controller.cpp]
2024-02-23 Resistance measurement graphics
2024-02-23 Timeout declaration for serial response limit
    -Timeout declaration for serial response limit
    -Graphics display errors
    -Exception management in preliminarycontrol ()
    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
    [controller.cpp, main.cpp]
2024-02-23 DS1302 setTime example
    Updated the Arduino sketch to set time on DS1302
2024-02-27 Adjust method to send parameters on serial
    -Fixed preliminary functions
    -Fixed graphic functions
    [controller.cpp]
2024-02-29 Files gerber for pcb added
    [logger_pcb_kicad-B_Adhesive.gbr, logger_pcb_kicad-B_Courtyard.gbr, logger_pcb_kicad-B_Cu.gbr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]
2024-02-29 V1.1.1
    Fixed serial (sending timestamp)
    Raised time before closing serial
    [controller.cpp]
2024-03-10 logger pcb files
    [logger schema.fzz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]
2024-03-19 fix controlResult + comment
    [controller.cpp]
2024-03-21 Fixed preliminary control function
    Fixed preliminary control function and some graphic settings
    [controller.cpp]
